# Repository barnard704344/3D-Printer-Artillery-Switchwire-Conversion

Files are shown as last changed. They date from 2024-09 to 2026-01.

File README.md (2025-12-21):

# 🚀 Artillery X1 → Voron Switchwire Conversion

This repository documents my journey converting my **Artillery X1** into a **Voron Switchwire**.

---

<details>
<summary>📜 Table of Contents (Click to expand)</summary>

- [📦 STLs](#-stls)
- [🖨️ Additional Printed Parts](#️-additional-printed-parts)
- [🛠 Build Plan](#-build-plan)
- [🔌 CAN Bus Setup](#-can-bus-setup)
- [🛤 MGN Rails](#-mgn-rails)
- [🍓 Raspberry Pi 4](#-raspberry-pi-4)
- [🖥 5" LCD – BTT TFT50](#-5-lcd--btt-tft50)
- [⚡ Power](#-power)
- [📏 2020 V-Slot Rail](#-2020-v-slot-rail)
- [🔩 Hardware](#-hardware)
- [🖼 Images](#-images)

</details>

---

## 📦 STLs
I have sourced, updated, and created everything needed for printing — **except** the Stealthburner:

🔗 [Voron Stealthburner](https://github.com/VoronDesign/Voron-Stealthburner)

---

## 🖨️ Additional Printed Parts

**BTT Cable Holders for CAN Bus Cable**  
- "CW2 cable bridge"  
- "Printed part for CAN cable"  
🔗 [BTT STL Files](https://github.com/bigtreetech/EBB/tree/master/EBB%20SB2240_2209%20CAN/STL)  

**Bowden Tube & CAN Bus Clips**  
🔗 [Printables Model](https://www.printables.com/model/741489-bowden-tube-and-canbus-usb-cable-support-clips/files)  

**Cable Clips for CAN Bus Wiring**  
🔗 [Printables Model](https://www.printables.com/model/538726-voron-2020-aluminum-profile-cable-clip-bigger-size)  

---

## 🛠 Build Plan

**To Keep**  
- 🖤 Base & frame  
- 🔥 Heatbed & glass bed *(will need a steel spring plate for Eddy sensor)*  
- ↔️ Y motion  
- ⬆️ Z steppers  
- 📟 MKS Gen L board & electronics  
- 📏 Optical endstops on Z & Y *(remove Z optical if using Eddy USB)*  

**To Add**  
- 🎭 Voron Stealthburner  
- 🧵 Voron Revo hotend  
- ⛔ Micro switch for X axis on toolhead  

---

## 🔌 CAN Bus Setup

- **BTT U2C USB Bridge**  
- **BTT EBB SB2209 RP2040**  
- Tutorial: [BTT EBB](https://github.com/bigtreetech/EBB)  

- **BTT Eddy Duo** (CAN Bus or USB)  
- Tutorial: [BTT Eddy](https://github.com/bigtreetech/Eddy)  
  - My Eddy coil uses I2C, so I wired it directly to the Raspberry Pi as the toolhead lacked I2C support.  

---

## 🛤 MGN Rails

- **Z Axis:** 2×MGN9 rails, 450mm  
- **X Axis:** 1×MGN12 rail, 350mm *(cut to 340mm)*  

---

## 🍓 Raspberry Pi 4

- Standard Raspberry Pi OS  
- Installed via [KIAUH](https://github.com/dw-0/kiauh) for Mainsail, Klipperscreen, Crowsnest, etc.  

---

## 🖥 5" LCD – BTT TFT50

- Remix of [this case](https://www.printables.com/model/198864-btt-tft50-v20-casehousing-mount-revision-2/files)  
- Remixed STLs are in the **electronics** folder  
- 30cm Raspberry Pi CSI cable  

---

## ⚡ Power

- 5V Meanwell PSU for Raspberry Pi  

---

## 📏 2020 V-Slot Rail

Replaces the 2060 X gantry:  
- 400mm cut to 380mm  

---

## 🔩 Hardware

**Screws & Inserts**  
- M5×45mm = 4  
- M5×16mm = 12 
- M5×30mm = 6  
- M3×8mm = get a pack of 50 (these are for the mgn rail )
- M3x12mm = 10
- M3x40mm = 3 (stealthurner mount)
- M3x15mm = 2 (these are for the belt holders on the stealthburner mount) 
- M3 nut = 3 (stealthburner mount)
- M3x6mm = 6 (stealthburner mounting)

- M3 Drop-in T-nuts  
- M5 Drop-in T-nuts  
- M3 Heat-set inserts × 20 *(standard Voron size - stealthburner mount, BTT eddy mount, Stealthburner )*  

**You will also need vitamins for the stealthburner (screws bolts etc, please check their github) 

**Bearings & Belts**  
- **F695-2RS Bearings** = 16  
  - Or use this kit (6 tooth GT2 & 2 smooth): [AliExpress Link](https://www.aliexpress.com/item/1005005767406346.html)  
- GT2 Belt = 5m  

---

## 🖼 Images  

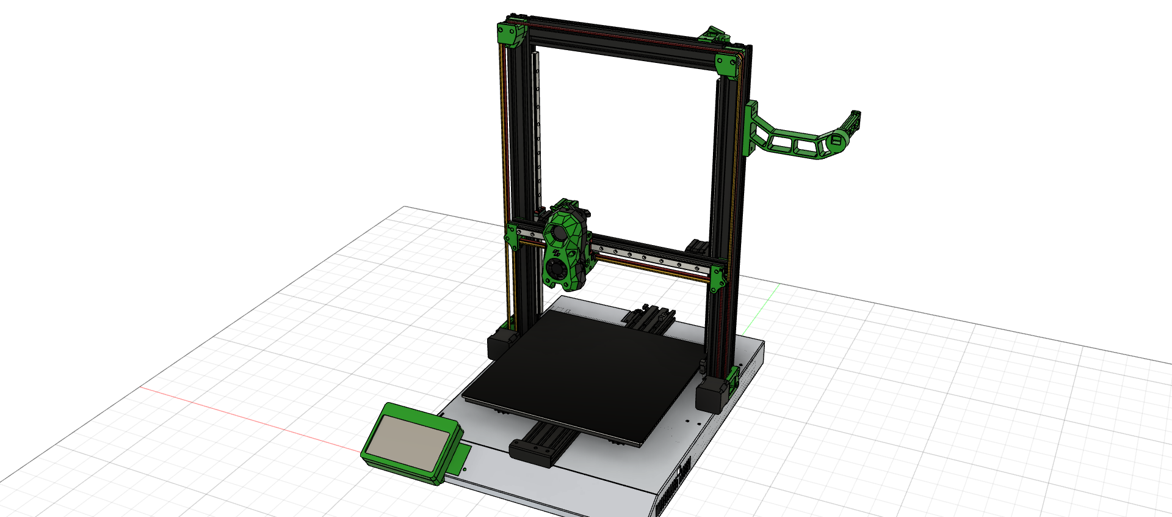
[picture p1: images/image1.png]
  
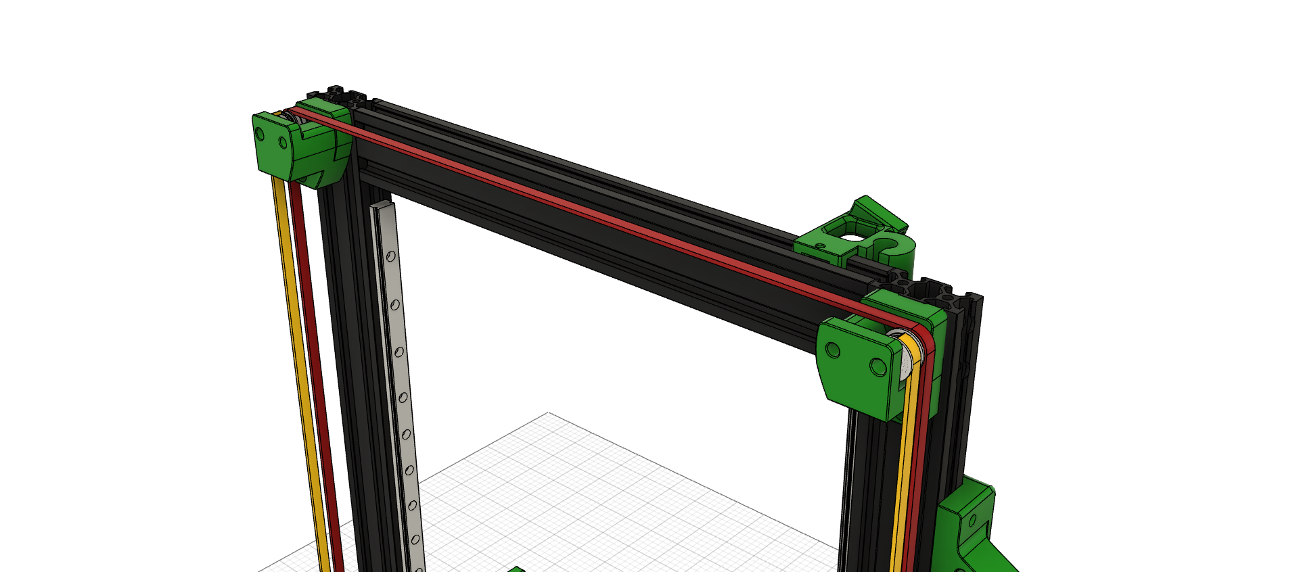
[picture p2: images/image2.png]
  
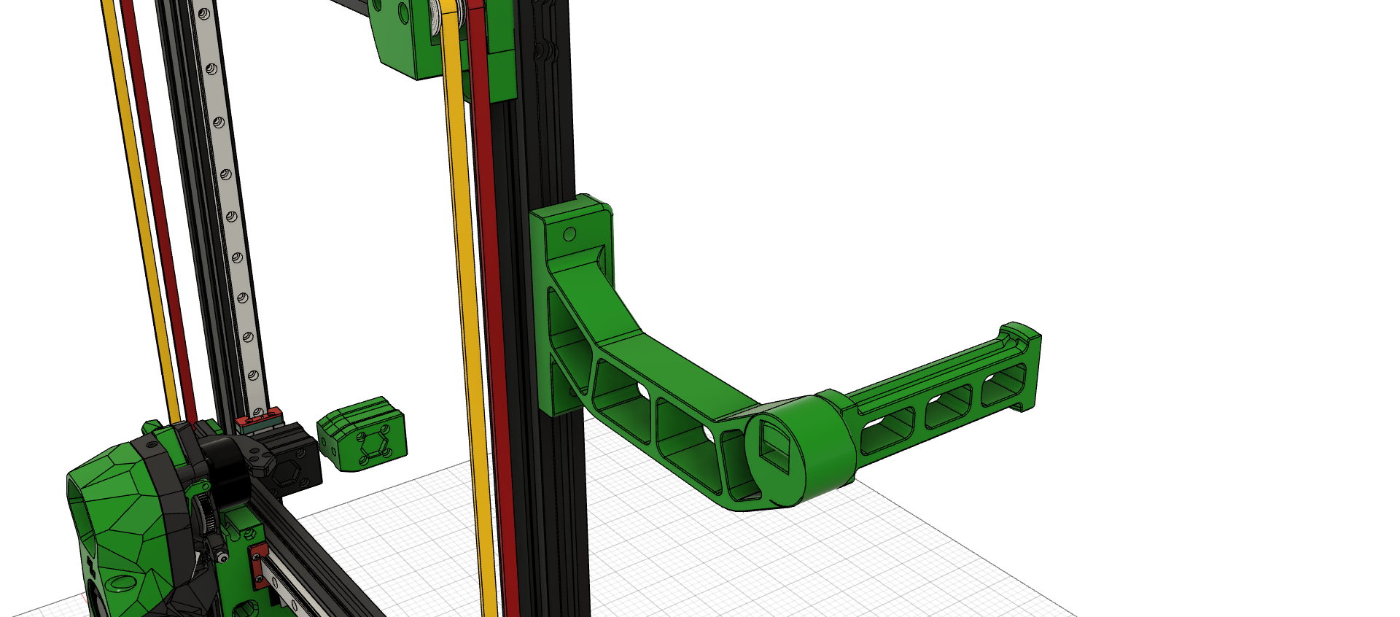
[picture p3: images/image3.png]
  
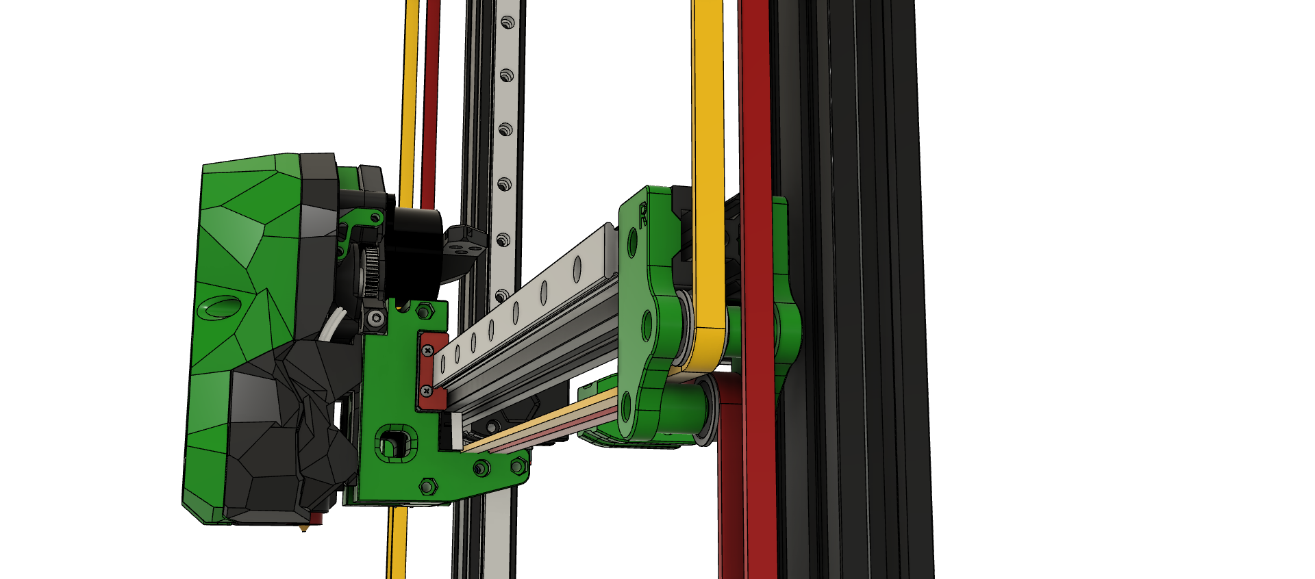
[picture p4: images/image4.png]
  
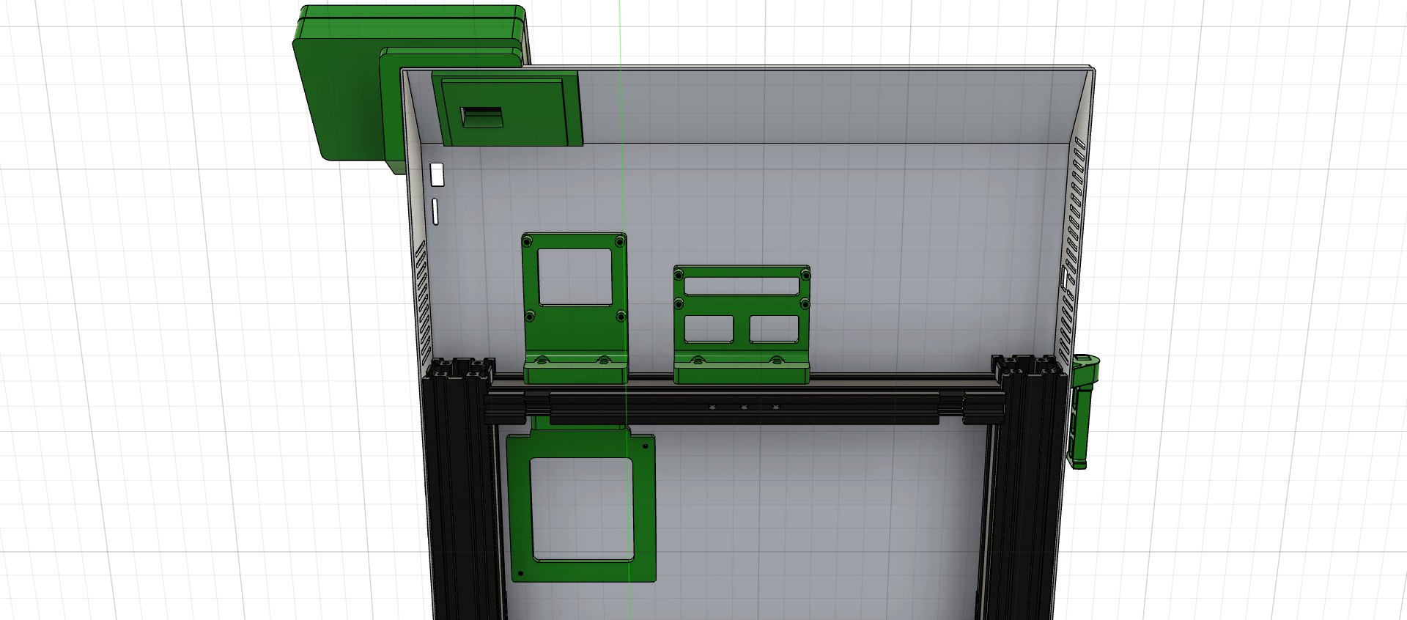
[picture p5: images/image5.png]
  
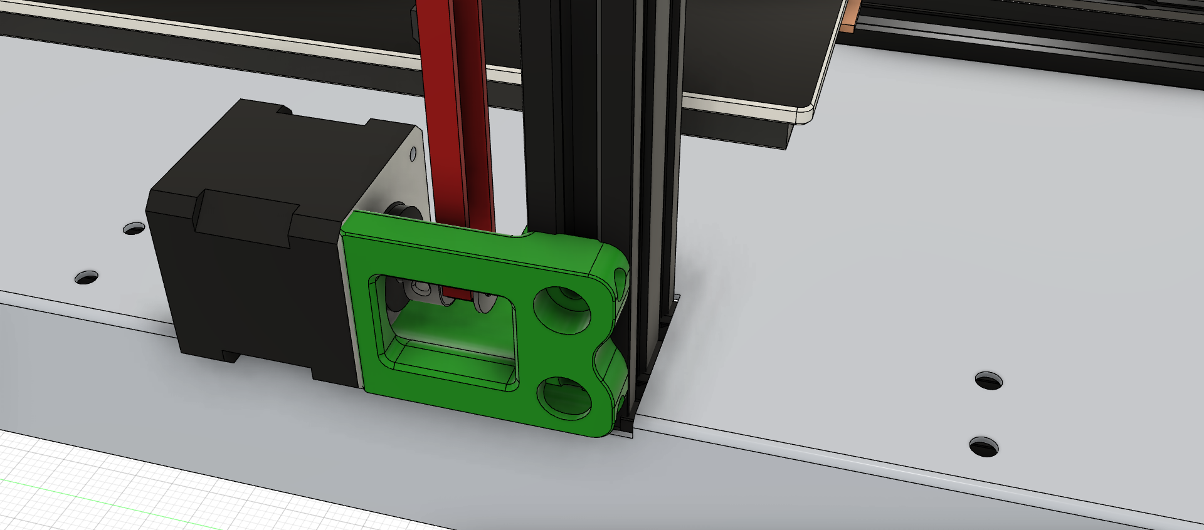
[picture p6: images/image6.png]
  

---

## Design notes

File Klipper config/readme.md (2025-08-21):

### OrcaSlicer

In OrcaSlicer go to "Printer settings" → "Machine start g-code" and update it to:

```gcode
M104 S0 ; Stops OrcaSlicer from sending temp waits separately
M140 S0
print_start EXTRUDER=[first_layer_temperature] BED=[first_layer_bed_temperature]
```

### rpi.cfg

Only use the rpi.cfg if you are using the Pi as an additional MCU.

I had a spare Eddy I2C coil, so I wired it straight through to the RPi. 
I don't recommend this approach - I have built two of these conversions and I could only get I2C to work on one of them.
Switching out to an Eddy USB was much easier.

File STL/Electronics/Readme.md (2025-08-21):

### Electronics Mounting

- I used M5 drop-in T-nuts and M5×16mm screws for the mounts
- I removed the welded mounts for the MKS Gen L and used a printed mount. This gave access to the USB port to be able to keep everything underneath.
- Don't forget your common ground between the 24V power and 5V power supplies

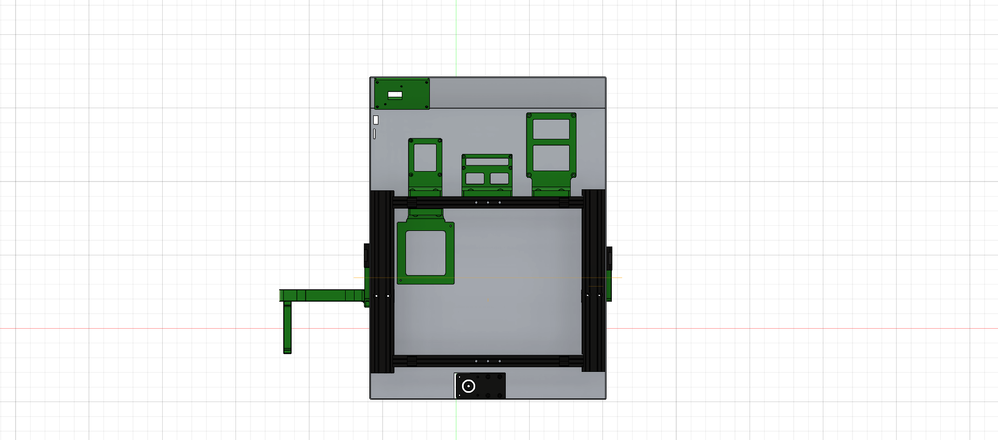
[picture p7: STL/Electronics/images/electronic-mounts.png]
Electronics mounts

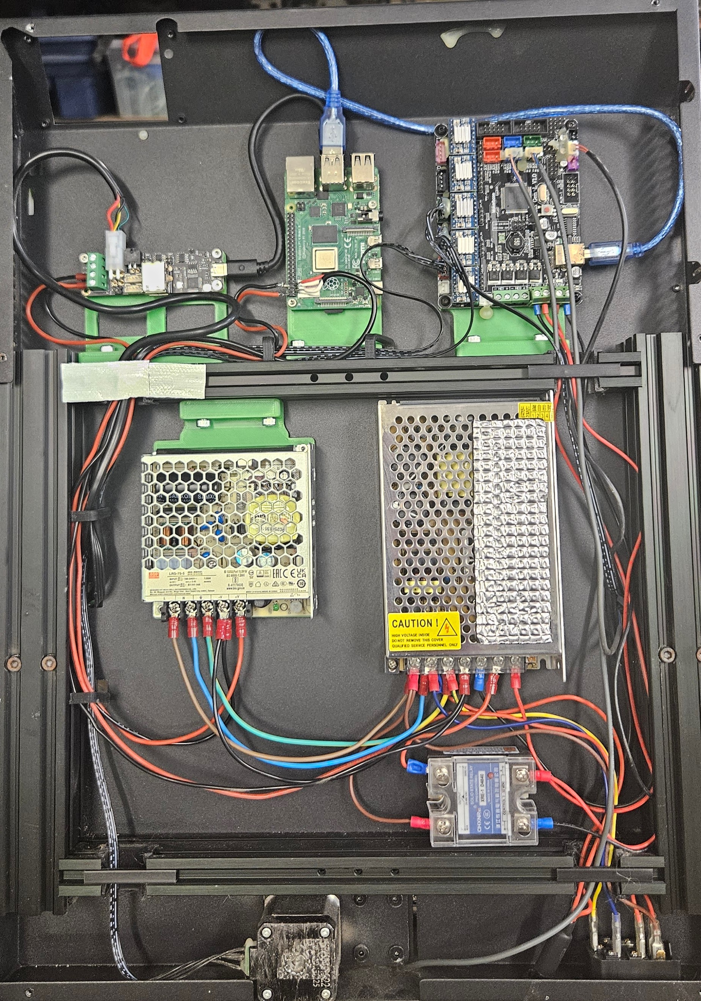
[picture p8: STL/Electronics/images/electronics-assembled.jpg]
Electronics assembled


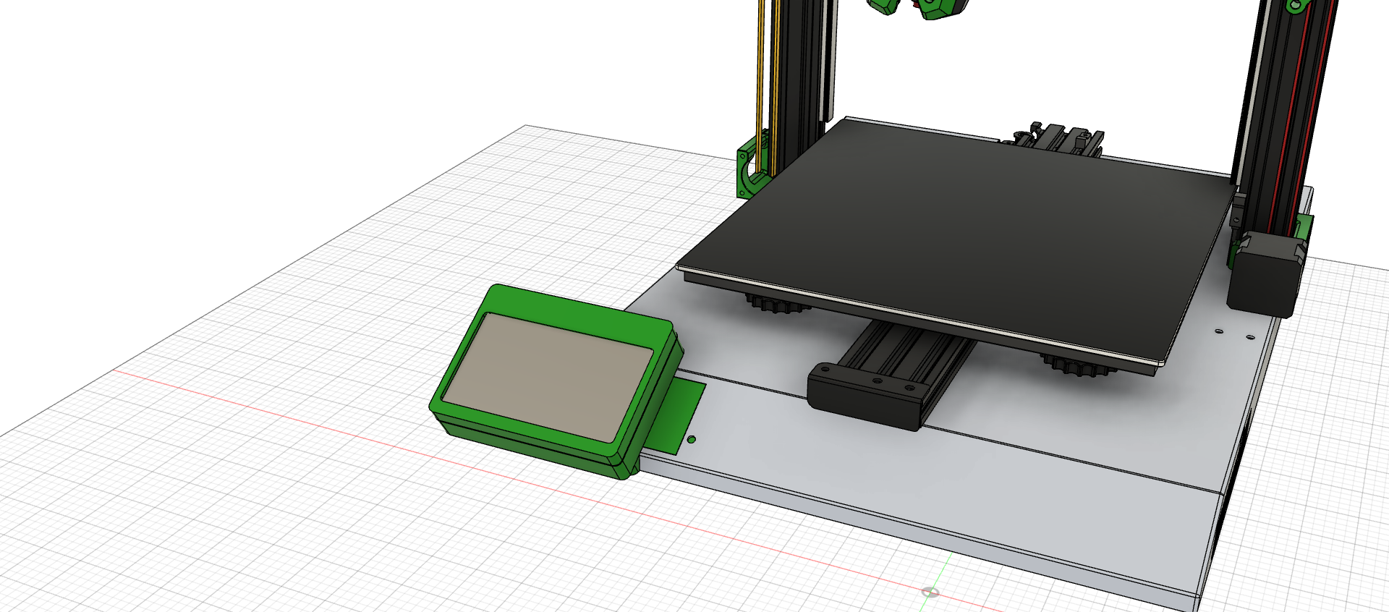
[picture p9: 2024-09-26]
images/Artilley X1 Switchwire conversion v109.png

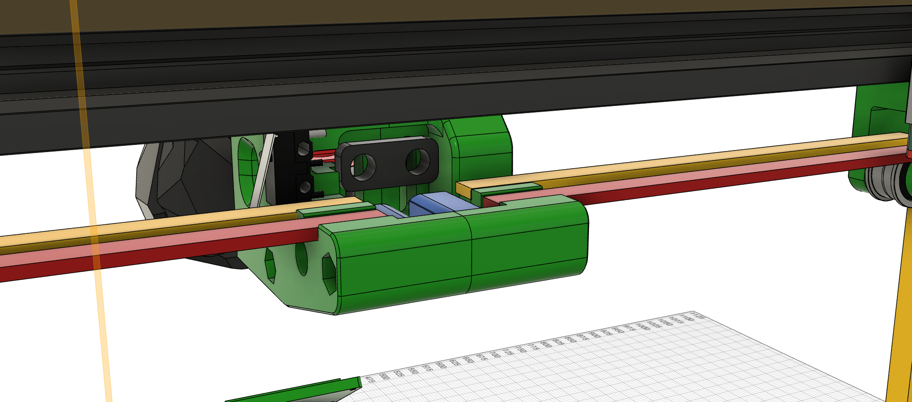
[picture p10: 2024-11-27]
STL/X Carriage/probe holder location.png

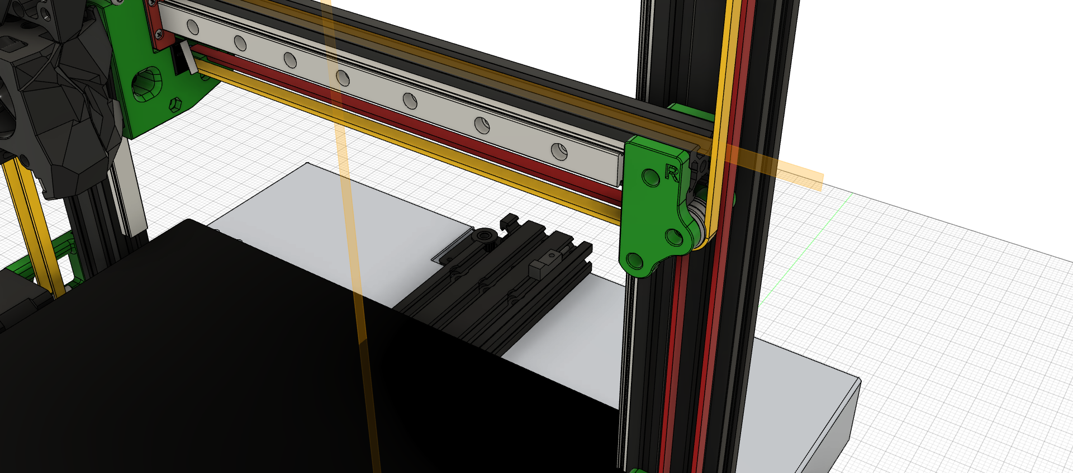
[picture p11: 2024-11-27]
STL/X Carriage/Right X carriage.png

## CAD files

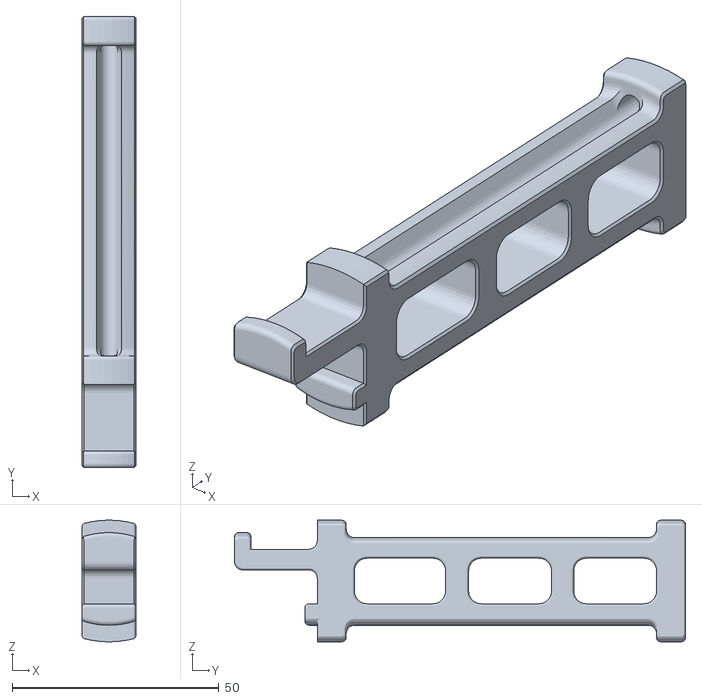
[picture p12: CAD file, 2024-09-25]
STL/Spool holder/filament arm spool.stl
13.0 x 109.0 x 29.4

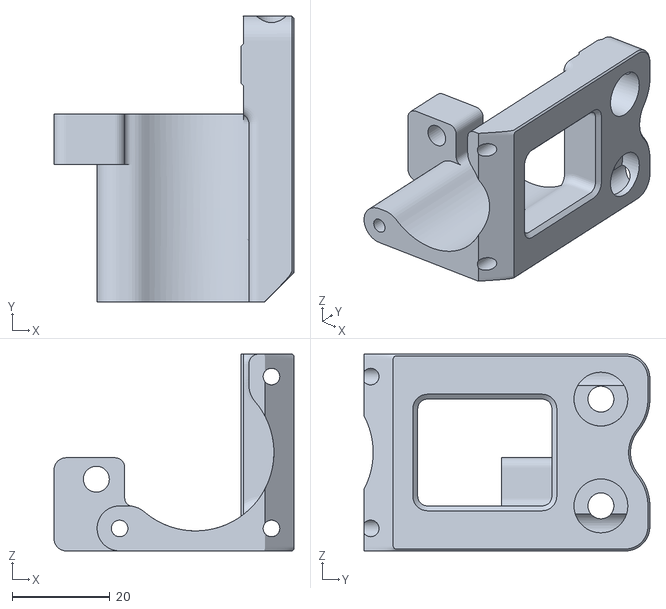
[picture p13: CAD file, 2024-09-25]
STL/Stepper Mounts/Right Stepper mount.stl
49.0 x 58.3 x 40.2

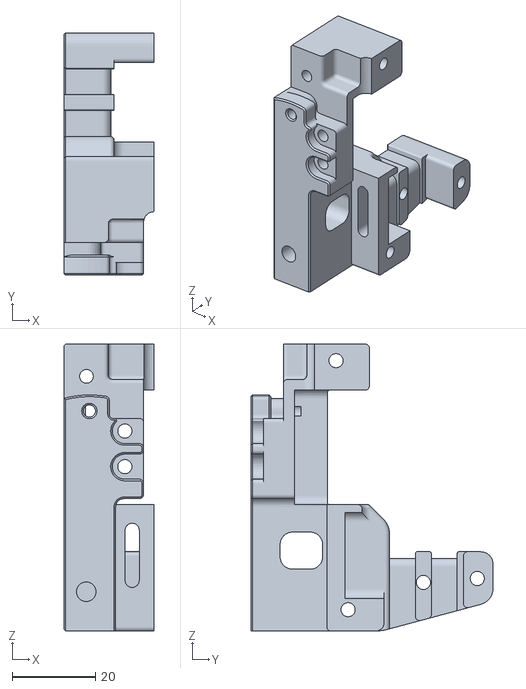
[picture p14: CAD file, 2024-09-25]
STL/X Carriage/X Carriage left toolhead.stl
21.6 x 58.0 x 68.8

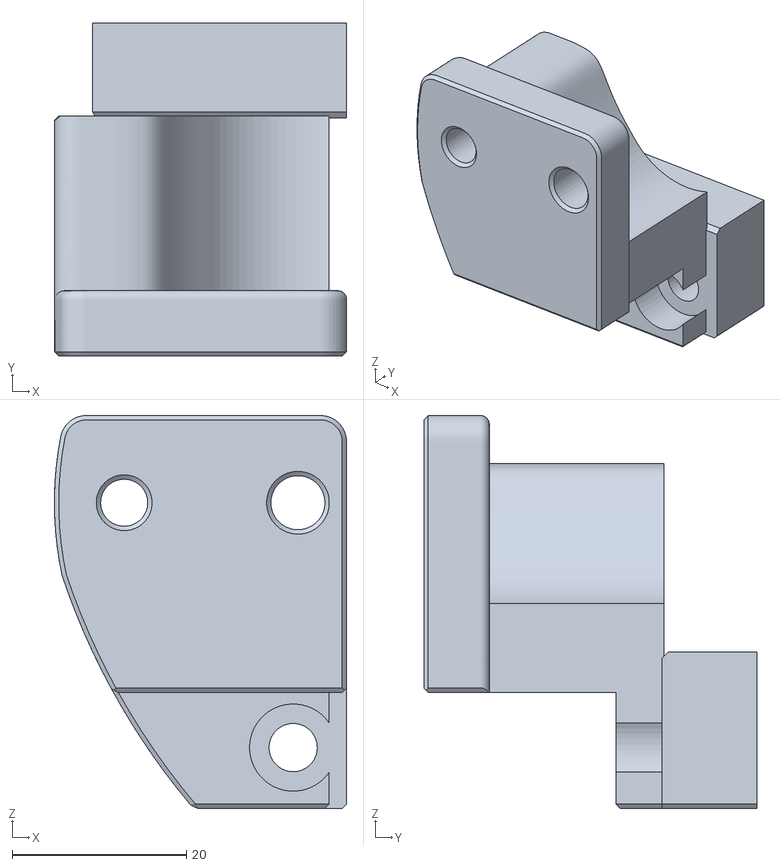
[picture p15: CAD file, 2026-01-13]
STL/XZ Carriage/Right Upper Block Front.stl
33.5 x 38.2 x 45.1

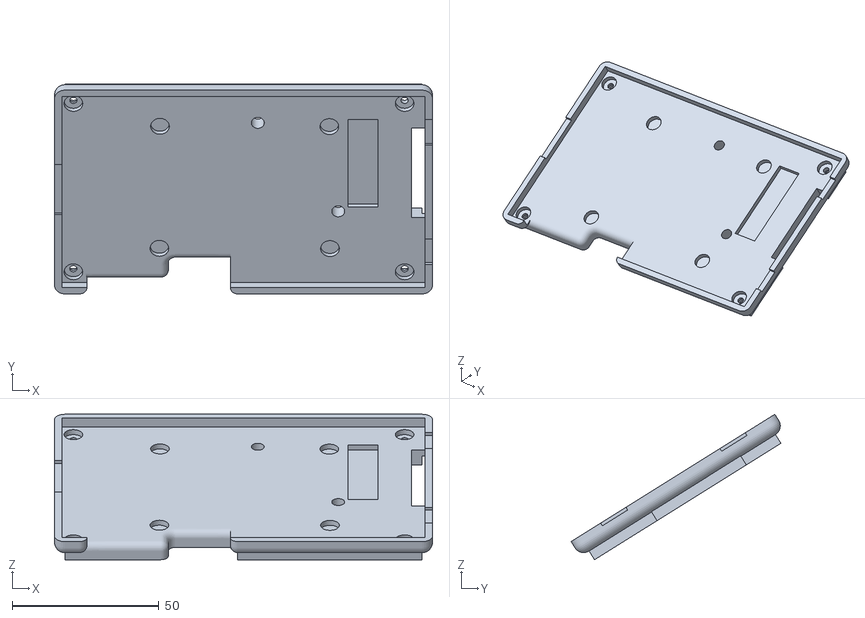
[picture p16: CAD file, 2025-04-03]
STL/Electronics/btt tft 50 base.stl
129.0 x 71.6 x 49.7

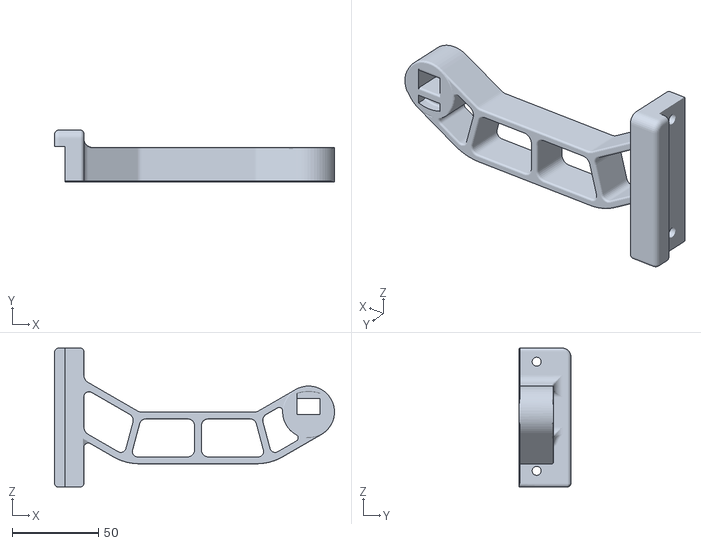
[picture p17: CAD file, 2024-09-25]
STL/Spool holder/fillament mount arm.stl
162.0 x 30.0 x 80.4

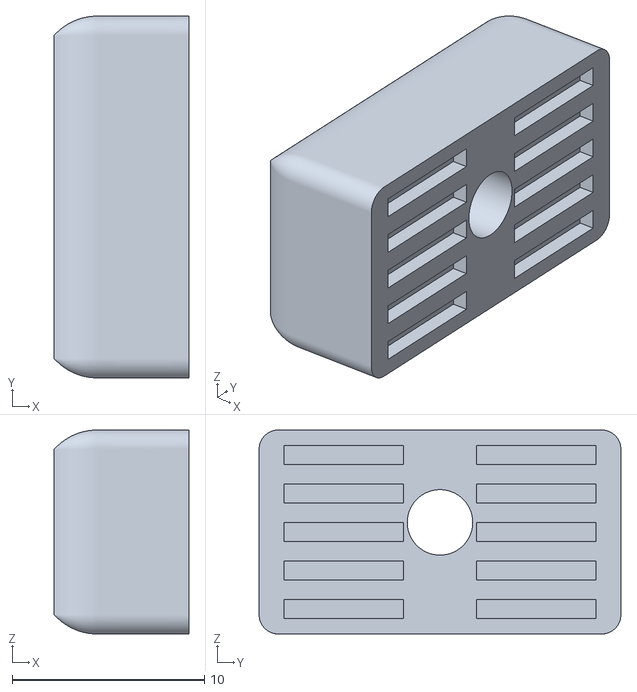
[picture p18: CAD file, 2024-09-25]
STL/X Carriage/gt2 belt holder.stl
7.00 x 18.8 x 10.6

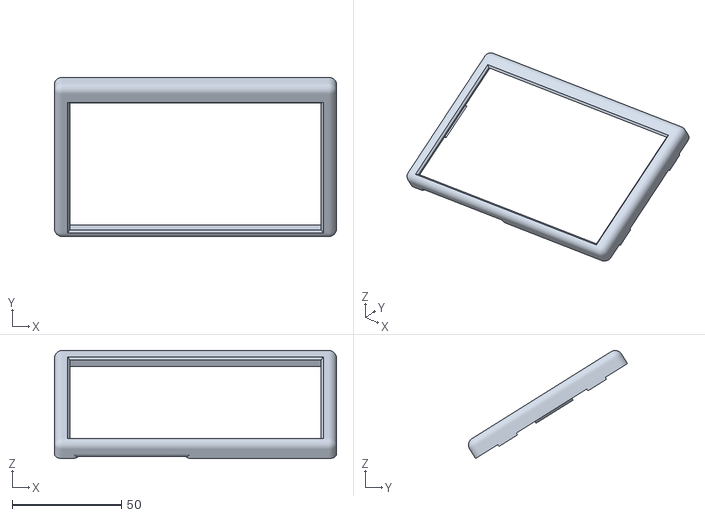
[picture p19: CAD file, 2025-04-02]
STL/Electronics/btt tft 50 lid.stl
129.0 x 72.8 x 49.4

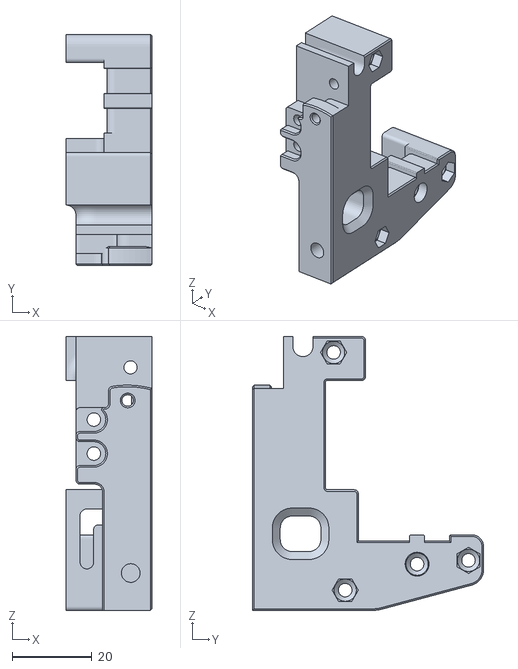
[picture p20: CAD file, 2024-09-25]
STL/X Carriage/X carriage right tool head.stl
21.6 x 58.0 x 68.8

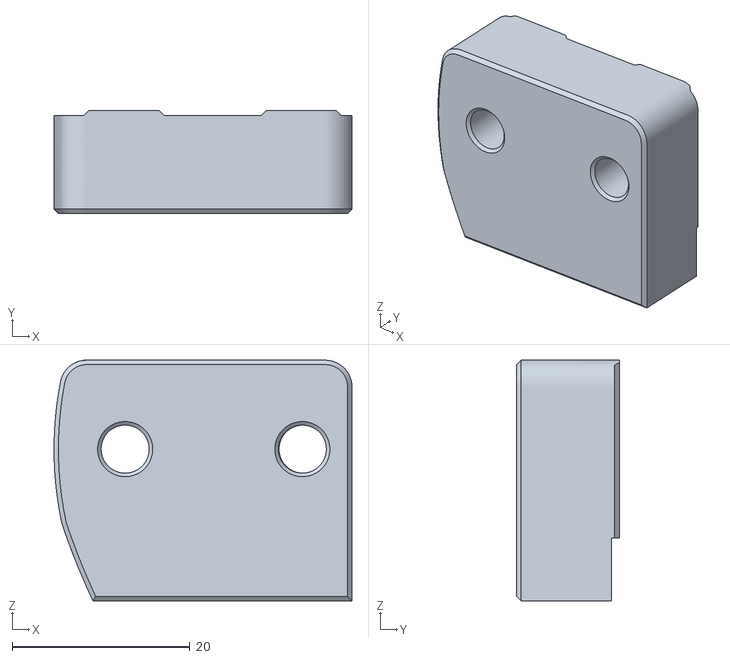
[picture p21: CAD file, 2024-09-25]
STL/XZ Carriage/Right Upper Block Rear.stl
33.5 x 11.6 x 27.1

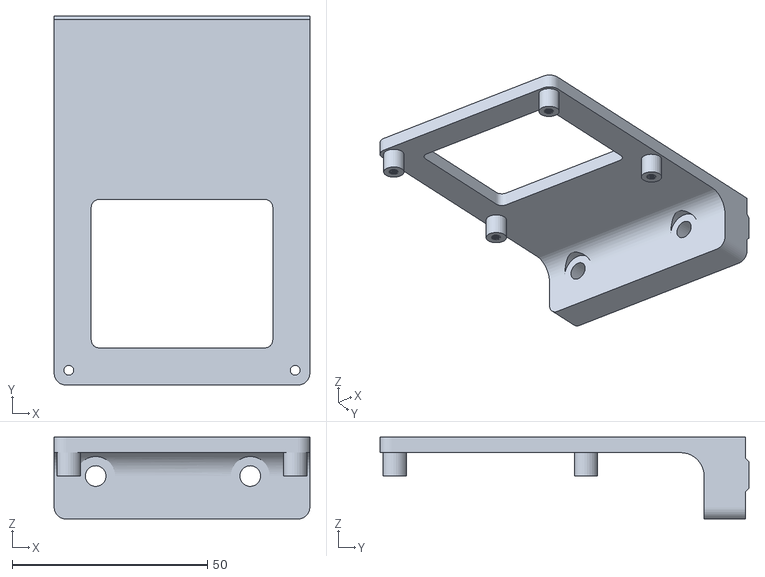
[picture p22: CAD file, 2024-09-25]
STL/Electronics/RPI mount.stl
65.5 x 94.5 x 21.0

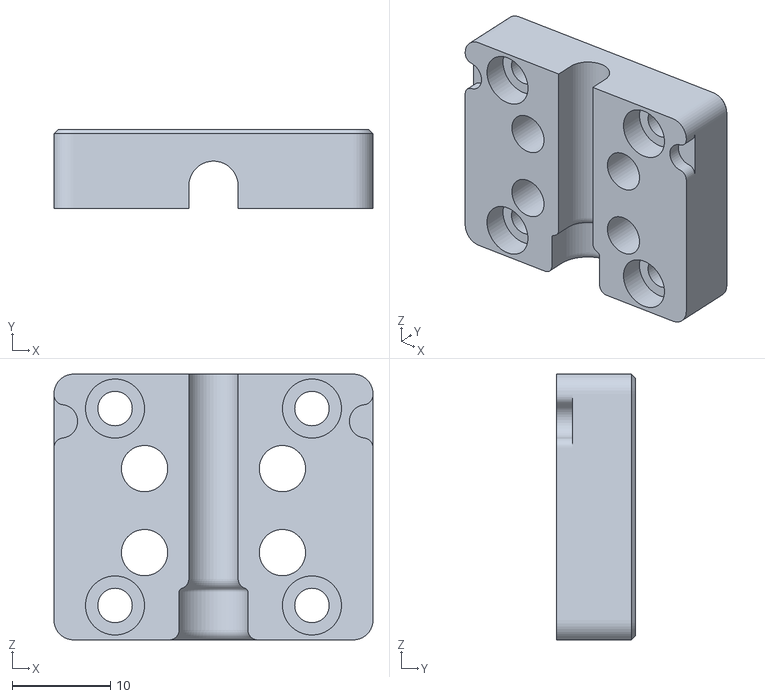
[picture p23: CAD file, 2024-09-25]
STL/X Carriage/x MGN mount.stl
32.4 x 8.00 x 27.0

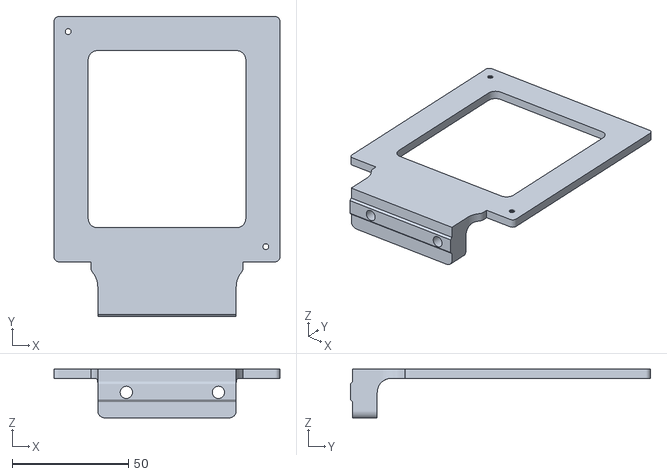
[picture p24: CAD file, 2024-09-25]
STL/Electronics/5v Meanwell power.stl
97.1 x 129.0 x 21.0

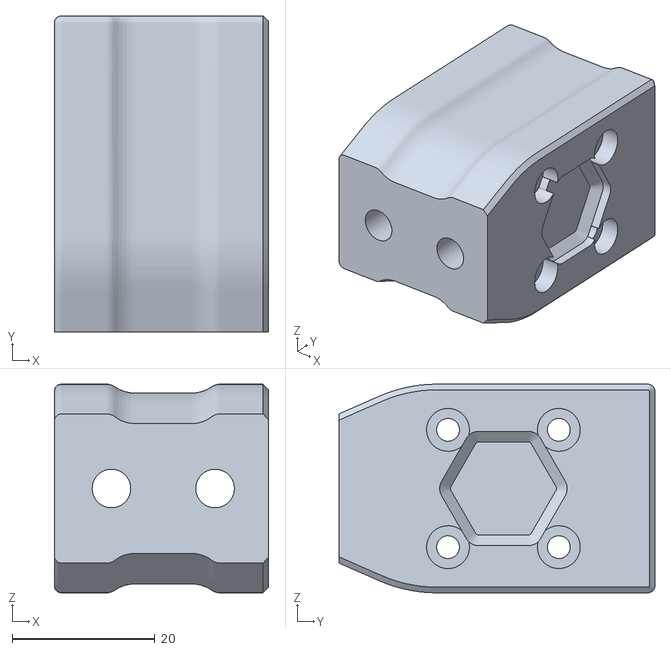
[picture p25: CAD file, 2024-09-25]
STL/X Carriage/X Carriage MGN 9 mounts- X2 Mirror.stl
30.0 x 44.2 x 29.2

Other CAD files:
STL/Stepper Mounts/left stepper mount.stl
STL/XZ Carriage/Left Upper Block Front.stl
STL/X Carriage/gt2 belt holder left.stl
STL/XZ Carriage/Left Upper block rear.stl
STL/Electronics/U2c Mount.stl
STL/Electronics/old screen blank.stl
STL/Electronics/old screen filler.stl

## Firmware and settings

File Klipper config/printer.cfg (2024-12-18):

[include mainsail.cfg]
[include ebb.cfg]
#uncomment if you are using the RPI as a secondary MCU
#[include rpi.cfg]
[include eddy.cfg]


[virtual_sdcard]
path: /home/pi/printer_data/gcodes

[temperature_sensor raspberry_pi]
sensor_type: temperature_host
min_temp: 10
max_temp: 100

[display_status]

[exclude_object]

[mcu]
#make sure this reflects your serial port you found when flashing klipper
serial: /dev/serial/by-id/usb-1a86_USB_Serial-if00-port0

[printer]
kinematics: corexz
max_velocity: 5000
max_accel: 6000
max_z_velocity: 5000
max_z_accel: 6000
square_corner_velocity: 5 

[input_shaper]
shaper_freq_x: 63.0
shaper_type_x: ei
#shaper_freq_y: 34.6
#shaper_type_y: EI






#####################################################################
#   X Stepper Settings
#####################################################################

######
# Motor -XM
# Endstop - X-STOP
###############
[stepper_x]
rotation_distance: 80
full_steps_per_rotation: 200
microsteps: 32
#step_pin: PL3
#dir_pin: PL1
#enable_pin: !PK0
step_pin: PF0
dir_pin: !PF1
enable_pin: !PD7
#endstop_pin: ^!PD3
endstop_pin: ^EBBCan:gpio24
position_endstop: 280
position_max: 280
position_min: 0
homing_speed: 50
second_homing_speed: 1


#####################################################################
#   Y Stepper Settings
#####################################################################

######
# Motor -YM
# Endstop - Y-STOP
###############
[stepper_y]
rotation_distance: 80
full_steps_per_rotation: 200
microsteps: 32
step_pin: PF6
dir_pin: PF7
enable_pin: !PF2
endstop_pin: ^!PJ1
position_endstop: 0
position_max: 300
position_min: 0
homing_speed: 50
#homing_positive_dir: true


#####################################################################
#   Z Stepper Settings
#####################################################################

######
# Motor -ZAM
# Endstop - Z-STOP
###############
[stepper_z] #Z input
rotation_distance: 80
full_steps_per_rotation: 200
microsteps: 32
#step_pin: PF0
#dir_pin: PF1
#enable_pin: !PD7
step_pin: PL3
dir_pin: !PL1
enable_pin: !PK0
#endstop_pin: probe:z_virtual_endstop
endstop_pin: ^!PD3 
position_endstop: 0
position_max: 280
position_min: -1
homing_speed: 50.0


[heater_bed]
heater_pin: PH5
sensor_type: EPCOS 100K B57560G104F
sensor_pin: PK6
min_temp: 0
max_temp: 150
#control: pid
#pid_Kp: 54.027
#pid_Ki: 0.770
#pid_Kd: 948.182

[fan]
pin: EBBCan:gpio13



[bed_screws]
screw1: 55,55
screw1_name: front left
screw2: 255,55
screw2_name: front right
screw3: 255,255
screw3_name: back right
screw4: 55,255
screw4_name: back left
speed: 100.0

[input_shaper]
shaper_freq_x: 24.7
shaper_freq_y: 24.7
shaper_type: mzv


# Support for gcode arc (G2/G3) commands.
[gcode_arcs]
resolution: 0.05
#   An arc will be split into segments. Each segment's length will
#   equal the resolution in mm set above. Lower values will produce a
#   finer arc, but also more work for your machine. Arcs smaller than
#   the configured value will become straight lines. The default is
#   1mm.


[homing_override]
gcode:
    G1 Z10 ; Move up 10mm
    G28 X Y
    G1 X140 Y170 F6000 ; Change the X and Y coordinates to the center of your print 
    G28 Z0
set_position_z: 0.0

#####################################################################
#   Macros
#####################################################################

[gcode_macro PRINT_START]
# Use PRINT_START for the slicer starting script - PLEASE CUSTOMISE THE SCRIPT
gcode:
  # This part fetches data from your slicer. Such as bed, extruder, and chamber temps and size of your printer.
  {% set target_bed = params.BED|int %}
  {% set target_extruder = params.EXTRUDER|int %}
  {% set x_wait = printer.toolhead.axis_maximum.x|float / 2 %}
  {% set y_wait = printer.toolhead.axis_maximum.y|float / 2 %}
  
  G28                                                   # Full home (XYZ)
  G90                                                   # Absolute position
  
  # Set bed temperature and wait for it to reach the target
  M140 S{target_bed}                                   # Set bed temperature
  M190 S{target_bed}                                   # Wait for bed temperature to reach target

  G1 X{x_wait} Y{y_wait} Z15 F9000                      # Go to center of the bed
  M107                                                  # Turn off part cooling fan
  M109 S{target_extruder}                               # Heat the hotend to set temp

  BED_MESH_CALIBRATE METHOD=rapid_scan ADAPTIVE=1
  
  G0 X{x_wait - 50} Y4 F10000                           # Go to starting point
  G0 Z0.4                                               # Raise Z to 0.4
  G91                                                   # Incremental positioning 
  G1 X100 E20 F1000                                     # Primeline
  G90                                                   # Absolute position



[gcode_macro PRINT_END]
#   Use PRINT_END for the slicer ending script
gcode:
    #   Get Boundaries
    {% set max_x = printer.configfile.config["stepper_x"]["position_max"]|float %}
    {% set max_y = printer.configfile.config["stepper_y"]["position_max"]|float %}
    {% set max_z = printer.configfile.config["stepper_z"]["position_max"]|float %}
    
    #   Check end position to determine safe directions to move
    {% if printer.toolhead.position.x < (max_x - 20) %}
        {% set x_safe = 20.0 %}
    {% else %}
        {% set x_safe = -20.0 %}
    {% endif %}

    {% if printer.toolhead.position.y < (max_y - 20) %}
        {% set y_safe = 20.0 %}
    {% else %}
        {% set y_safe = -20.0 %}
    {% endif %}

    {% if printer.toolhead.position.z < (max_z - 2) %}
        {% set z_safe = 2.0 %}
    {% else %}
        {% set z_safe = max_z - printer.toolhead.position.z %}
    {% endif %}
    
    #  Commence PRINT_END
    M400                             ; wait for buffer to clear
    G92 E0                           ; zero the extruder
    G1 E-4.0 F3600                   ; retract
    G91                              ; relative positioning
    G0 Z{z_safe} F3600               ; move nozzle up
    G0 X{x_safe} Y{y_safe} F20000    ; move nozzle to remove stringing
    
    M104 S0                          ; turn off hotend
    M140 S0                          ; turn off bed
    M106 S0                          ; turn off fan
    G90                              ; absolute positioning
    G0 X{max_x / 2} Y{max_y} F3600   ; park nozzle at rear
    M117 Finished!

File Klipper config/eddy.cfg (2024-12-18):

# The MCU section only applies to the Eddy USB. For Eddy Coil you will use the MCU name of the toolboard that you connected the Eddy Coil to.
[mcu eddy]
serial: /dev/serial/by-id/usb-Klipper_rp2040_5044340310A6971C-if00  # This is the serial address of your eddy probe. This can be found by using the terminal of your klipper instance (typically through SSH) and using the command ```ls /dev/serial/by-id``` 
restart_method: command


[temperature_sensor btt_eddy_mcu]
sensor_type: temperature_mcu # Sets the type of sensor for Klipper to read
sensor_mcu: eddy # Sets the MCU of the eddy probe tempereature sensor
min_temp: 10 # Sets the minimum tempereature for eddys tempereature sensor to operate
max_temp: 100 # Sets the maximum tempereature for eddys tempereature sensor to operate

[probe_eddy_current btt_eddy]
sensor_type: ldc1612
z_offset: 2.5
#i2c_address:
i2c_mcu: eddy  # This value is good for the Eddy USB but would need to be adjusted for the Eddy Coil according to the MCU you have used.
i2c_bus: i2c0f # This value is good for the Eddy USB but would need to be adjusted for the Eddy Coil according to the I2C bus you have used.
# Measure the offsets below using the method described here: https://www.klipper3d.org/Probe_Calibrate.html#calibrating-probe-x-and-y-offsets
# For a standard Voron stealthburner X carriage mount there should be no need to change the defaults below.
x_offset: 0
y_offset: 21.42

# This section is only relevant for Eddy USB. Comment it out for Eddy Coil.
[temperature_probe btt_eddy]
sensor_type: Generic 3950
sensor_pin: eddy:gpio26
horizontal_move_z: 2

[bed_mesh]
horizontal_move_z: 2
speed: 200
# For the mesh dimensions below, the coordinates need to be reachable by the center of the probe. To calculate coordinates that will work, use the formula below:
# mesh x min = position_min_x + greater_of (15mm or x_offset) <--- in this term, only consider the x offset if it is positive, ignore if negative.
# mesh y min = position_min_y + greater_of (15mm or y_offset) <--- in this term, only consider the y offset if it is positive, ignore if negative.
# mesh x max = position_max_x - greater_of (15mm or |x_offset|) <--- in this term, only consider the x offset if it is negative, ignore if positive.
# mesh y max = position_max_y - greater_of (15mm or |y_offset|) <--- in this term, only consider the y offset if it is negative, ignore if positive.
# Example: Consider that you have a 300 x 300 bed with the max x and y positions being 300 and the min being 0. Your probe offsets are -20 for X and 10 for Y
# For mesh x min we ignore the x offset term because it is negative. Therefore mesh x min = 15
# For mesh y min we do not ignore the y offset term because it is positive but it is less than 15 so we use 15. Therefore mesh y min = 15
# For mesh x max we do not ignore the x offset term because it is negative. It is also greater than 15. Therefore mesh x max = 280
# For mesh y max we ignore the y offset term because it is positive but it is less than 15 so we use 15. Therefore mesh y max = 285
# The final result would be mesh_min: 15, 15 mesh_max: 280, 285
mesh_min: 5, 25  # modify these according to the above guide. If the probe cannot reach then you will get a klipper error when trying to scan a bed mesh.
mesh_max: 275, 300 # modify these according to the above guide. If the probe cannot reach then you will get a klipper error when trying to scan a bed mesh.
probe_count: 9, 9
algorithm: bicubic
#scan_overshoot: 8  #uncomment this section if you still have room left over on the X axis for some scan overshoot to product smoother movements and more accurate scanning. Uncommenting this should be fine if you are using a standard voron mount.

# Uncomment this if you are using Eddy as the probe AND the homing endstop
[safe_z_home]
home_xy_position: 150, 150 # Choose an X,Y position that is in the center of your bed. For a 300x300 machine that will be 150, 150. Use the same principle to calculate your bed center.
z_hop: 10
z_hop_speed: 25
speed: 200

###############################Macros and related################################
#This secton contains macros and related config sections. Some should be used, others are optional. Read the comment above each one to find out whether or not to uncomment it for your installation.


# Uncomment this if you are using Eddy as the probe AND the homing endstop AND would like to use the beta z-offset control
#[save_variables]
#filename: ~/printer_data/config/variables.cfg



# Uncomment this if you are using Eddy as the probe AND the homing endstop
[force_move]
enable_force_move: True # Allows a user to move the z axis down if they have no other means of homing Z and need to calibrate the Eddy.



# Uncomment this if you are using Eddy as the probe AND the homing endstop AND would like to use the beta z-offset control
#[delayed_gcode RESTORE_PROBE_OFFSET]
#initial_duration: 1.
#gcode:
#  {% set svv = printer.save_variables.variables %}
#  {% if not printer["gcode_macro SET_GCODE_OFFSET"].restored %}
#    SET_GCODE_VARIABLE MACRO=SET_GCODE_OFFSET VARIABLE=runtime_offset VALUE={ svv.nvm_offset|default(0) }
#    SET_GCODE_VARIABLE MACRO=SET_GCODE_OFFSET VARIABLE=restored VALUE=True
#  {% endif %}



# Uncomment this if you are using Eddy as the probe AND the homing endstop
# Take note of the lines that should only be used if you have a KNOMI installed.
[gcode_macro G28]
rename_existing: G28.1
gcode:
  #SET_GCODE_VARIABLE MACRO=_KNOMI_STATUS VARIABLE=homing VALUE=True # Uncomment this if using a KNOMI and then remove the G28 macro from the KNOMI.cfg
  G28.1 {rawparams}
  {% if not rawparams or (rawparams and 'Z' in rawparams) %}
    PROBE
    SET_Z_FROM_PROBE
  {% endif %}
  #SET_GCODE_VARIABLE MACRO=_KNOMI_STATUS VARIABLE=homing VALUE=False # Uncomment this if using a KNOMI and then remove the G28 macro from the KNOMI.cfg



# Uncomment this if you are using Eddy as the probe AND the homing endstop
[gcode_macro SET_Z_FROM_PROBE]
gcode:
    {% set cf = printer.configfile.settings %}
    SET_GCODE_OFFSET_ORIG Z={printer.probe.last_z_result - cf['probe_eddy_current btt_eddy'].z_offset + printer["gcode_macro SET_GCODE_OFFSET"].runtime_offset}
    G90
    G1 Z{cf.safe_z_home.z_hop}


# Uncomment this if you are using Eddy as the probe AND the homing endstop AND would like to use the beta z-offset control
#[gcode_macro Z_OFFSET_APPLY_PROBE]
#rename_existing: Z_OFFSET_APPLY_PROBE_ORIG
#gcode:
#  SAVE_VARIABLE VARIABLE=nvm_offset VALUE={ printer["gcode_macro SET_GCODE_OFFSET"].runtime_offset }



# Uncomment the lines in this macro if you are using Eddy as the probe AND the homing endstop AND would like to use the beta z-offset control
[gcode_macro SET_GCODE_OFFSET]
rename_existing: SET_GCODE_OFFSET_ORIG
variable_restored: False  # Mark whether the var has been restored from NVM
variable_runtime_offset: 0
gcode:
#  {% if params.Z_ADJUST %}
#    SET_GCODE_VARIABLE MACRO=SET_GCODE_OFFSET VARIABLE=runtime_offset VALUE={ printer["gcode_macro SET_GCODE_OFFSET"].runtime_offset + params.Z_ADJUST|float }
#  {% endif %}
#  {% if params.Z %}
#    {% set paramList = rawparams.split() %}
#    {% for i in range(paramList|length) %}
#      {% if paramList[i]=="Z=0" %}
#        {% set temp=paramList.pop(i) %}
#        {% set temp="Z_ADJUST=" + (-printer["gcode_macro SET_GCODE_OFFSET"].runtime_offset)|string %}
#        {% if paramList.append(temp) %}{% endif %}
#      {% endif %}
#    {% endfor %}
#    {% set rawparams=paramList|join(' ') %}
#    SET_GCODE_VARIABLE MACRO=SET_GCODE_OFFSET VARIABLE=runtime_offset VALUE=0
#  {% endif %}
  SET_GCODE_OFFSET_ORIG { rawparams }



# This macro automates a lot of the frequency mapping process and simplifies the steps significantly.
[gcode_macro PROBE_EDDY_CURRENT_CALIBRATE_AUTO]
gcode:
  BED_MESH_CLEAR
  G28 X Y
  G90 # Abs positioning
  G1 X{ printer.toolhead.axis_maximum.x/2 } Y{ printer.toolhead.axis_maximum.y/2 } F6000
  {% if 'z' not in printer.toolhead.homed_axes %}
    SET_KINEMATIC_POSITION Z={ printer.toolhead.axis_maximum.z-1 } # Allows the user to work it down until it touches.
  {% endif %}
  PROBE_EDDY_CURRENT_CALIBRATE {rawparams}



#This macro is optional but useful if you want to run a rapid scan before each print. Simply uncomment it and add BED_MESH_SCAN to your print start code.
#[gcode_macro BED_MESH_CALIBRATE]
#rename_existing: BTT_BED_MESH_CALIBRATE
#gcode:
#  SET_GCODE_VARIABLE MACRO=_KNOMI_STATUS VARIABLE=probing VALUE=True #Only uncomment this line if using a KNOMI and then remove the BED_MESH_CALIBRATE macro from KNOMI.cfg
#  BTT_BED_MESH_CALIBRATE METHOD=rapid_scan
#  SET_GCODE_VARIABLE MACRO=_KNOMI_STATUS VARIABLE=probing VALUE=False #Only uncomment this line if using a KNOMI and then remove the BED_MESH_CALIBRATE macro from KNOMI.cfg

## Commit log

2024-09-25 update STL
    [5v Meanwell power.stl, Artilley X1 Switchwire conversion v100.stl, Body89.stl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]
2024-11-01 update to printer.cfg
    [ebb.cfg, printer.cfg]
2024-11-01 update printer.cfg for correct X Y
    [printer.cfg]
2024-11-06 Create Voron Switchwire 300 0.4 nozzle.orca_printer
    orca 2.2 config
2024-11-14 update stls
    updated blanking plate and screen mount
    [old screen filler.stl, screeen mount.stl]
2024-11-14 Update Voron Switchwire 300 0.4 nozzle.orca_printer
2024-11-14 update configs
    [ebb.cfg, printer.cfg, rpi.cfg]
2024-11-27 update ptfe tube holder
    [Body89.stl]
2024-11-27 Create old screen blank.stl
    [old screen blank.stl]
2024-11-27 Create probe holder.stl
2024-11-27 Create probe holder.png
2024-11-27 update probe holder
2024-11-27 updates
    updates to X carriage parts
2025-04-02 Update btt tft 50 base.stl
    [btt tft 50 base.stl]
2025-12-02 Add configuration for Voron Switchwire 300 0.4 nozzle
2025-12-21 Revise screw and insert quantities in README
    Updated hardware specifications for screws and inserts.
2026-01-13 small update to improve belt clearance
    Right upper block and left upper block - front
    [Left Upper Block Front.stl, Right Upper Block Front.stl]
2026-01-13 moved screw holes
    Allows the BTT screen to sit lower, so the bed clears the top of the surround
    [old screen filler.stl]
